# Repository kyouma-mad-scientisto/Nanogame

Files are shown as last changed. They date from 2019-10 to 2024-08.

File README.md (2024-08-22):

# Nanogame

Da einige meiner Freunde interesse am Programmieren mit Arduino zeigten, habe ich vor einiger Zeit einen kleinen Workshop organisiert und für diesen Zweck eine eigene Platine als Plattform für diverse Module konstruiert.<br />

Diese Hardware-Plattform bietet Platz für:<br />

1x Arduino Nano<br />
1x DFPlayer Mini (zur Audiowiedergabe von microSD)<br />
1x PCD8544 LC-Display<br />
1x TP4056 Li-Ion Laderegler<br />
1x Step-Up Wandler (5V für Arduino Nano)<br />

Als Grundlage sind auf der Platine 11 Tasten vorhanden, ein microSD Kartenslot sowie die benötigte Außenbeschaltung.<br />
Um IOs zu sparen, werden die Tasten über Schieberegister abgefragt, so werden nur 3 IOs benötigt.<br />

Alle noch freien IOs habe ich auf einen Pin Header auf der Rückseite gelegt.<br />

Um das ganze Testen zu können, habe ich Snake, bzw. ein Snake ähnliches Spiel, implementiert. (Siehe Demo Video und Code unter Beispiele)<br />

Hier die fehlerbehaftete erste Variante der Leiterplatte die ich noch zu Hause hergestellt habe:<br />

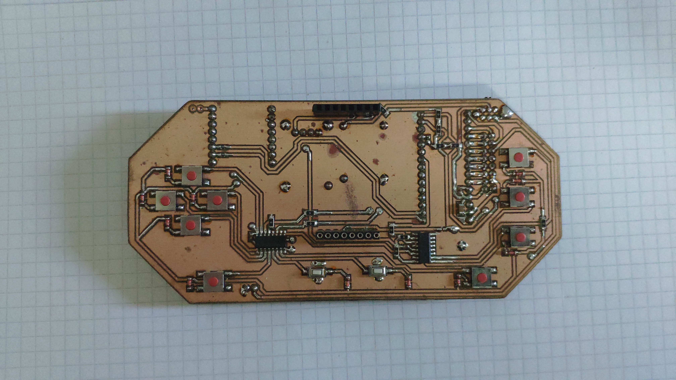
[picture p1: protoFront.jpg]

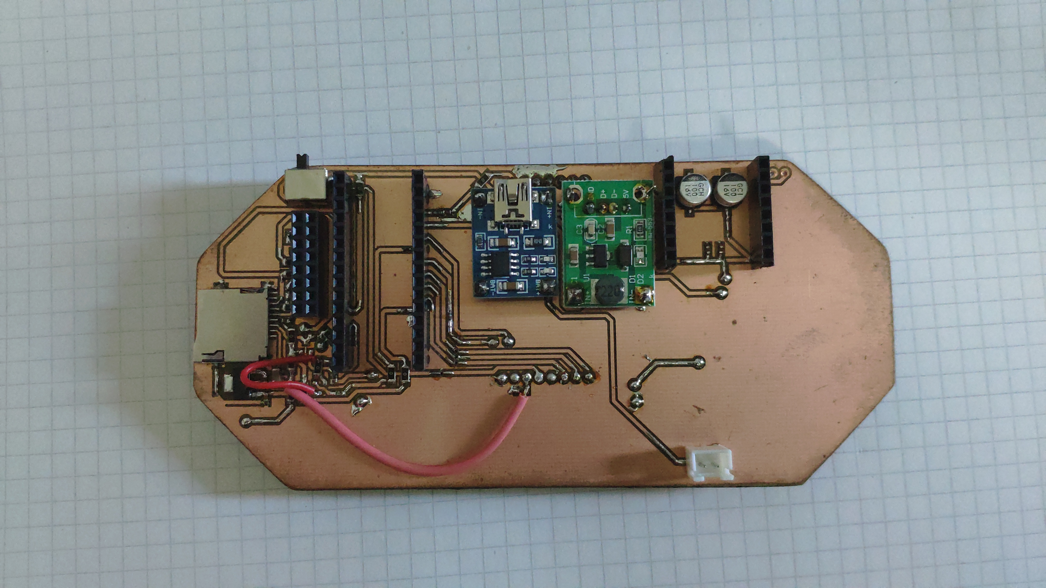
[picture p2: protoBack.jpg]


Hier nun die fertige Variante vom professionellen Leiterplattenfertiger:<br />

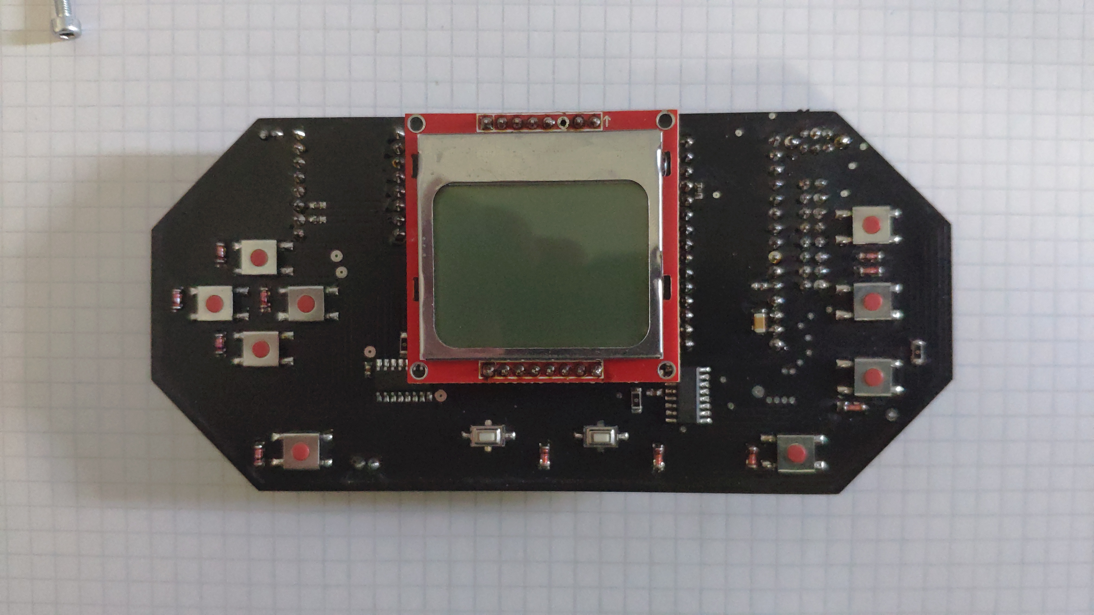
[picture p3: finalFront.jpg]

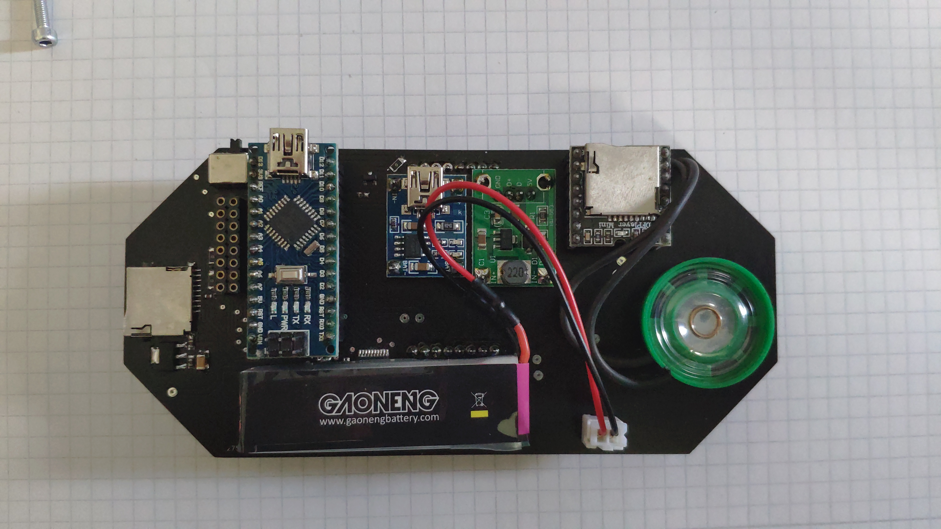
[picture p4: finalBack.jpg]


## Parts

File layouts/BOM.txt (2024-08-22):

Pos.		Bezeichnung/Bauform			Wert		Menge

1		DFPlayerMini				-		1
2		SMD Elektrolytkondensator		16V/100µF	2
3		Schottky-Diode				40V/1A		1
4		Keramikkondensator/0603			50V/100nF	10
5		Diode 1N4001/1206			50V/1A		11
6		SMD Taster 6x6mm			-		9
7		SMD Taster 6x3mm			-		2
8		PCD8544 LCD				Vcc = 3,3V	1
9		Brücken/1206				0 Ohm		12
10		IRLML2502PBF/SOT23			-		1
11		Widerstand/0603				85 Ohm		1
12		AMS1117-3.3				3,3V LDO	1
13		Keramikkondensator/1206			25V/10µF	2
14		Widerstand/0603				100kOhm		1
15		Widerstand/0603				200kOhm		1
16		JST Steckbuchse				2pol.		1
17		Schalter				2 Wechsler	1
18		Li-Ion Lademodul			500mA		1
19		Aufwärtsschaltspannungswandlermodul	5V/200mA	1
20		Widerstand/0603				1kOhm		2
21		microSD Kartenslot 			Retention	1
22		Arduino Nano 				Atmega328p	1
23		74HC595D Schieberegister		-		2
24		Pegelwandler TXS0108EPWR		bidirektional	1
25		Steckerleiste				16 pol. (2x8)	1
26		Widerstand/0603				10kOhm		1		<--- wurde auf 10kOhm geändert, im Layout als 200kOhm für Taster Eingang

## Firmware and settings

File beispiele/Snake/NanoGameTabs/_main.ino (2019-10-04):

#include <avr/interrupt.h>
#include <avr/io.h>
#include <Arduino.h>
//############################################################################################################################################################################

//Snake Instanz anlegen
Snake snake;

void setup() {
//Timer2 fuer 1ms initialisieren
  Timer2.initTimer2();
  Timer2.enableTimer2Interrupt();
//Hintergrundbeleuchtung pwm
  pwmBL.initOCR1B();
//Pegelwandler ein
  pinMode(_OE_LEVEL, OUTPUT);
  digitalWrite(_OE_LEVEL, HIGH);
//Hintergrundbeleuchtung an, halbe Helligkeit  
  pinMode(BL, OUTPUT);
  BRIGHTNESS = 127;
//LCD init,   invert, vop, tempcoef, bias  
  lcd.begin(false, 0xB1, 0x04, 0x12);
  lcd.clear();
//erster Taster check
  tasten.checkButtons();
//DFPlayer mini initialisieren
#ifdef SOUND
  Serial.begin(9600);   //set speed for Hardware  Serial pin 1 and 2 tx/rx
  myDFPlayer.begin(Serial);//select Serial to send comand to dfplayer
  myDFPlayer.EQ(DFPLAYER_EQ_ROCK);
#endif
  snake.startGame();
}
//Endlosschleife
void loop() {
  snake.runningGame();
}

ISR(TIMER2_COMPA_vect) { // called by timer2
  tasten.checkButtons();  //Aufruf 1-mal pro Millisekunde
  snake.increaseTimer();
}

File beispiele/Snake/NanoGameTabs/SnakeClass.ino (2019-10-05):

#include <Coordinates.h>
#include <EEPROM.h>
//defines fuer die Richtung in die die Schlange kriecht
#define UP 0
#define DOWN 1
#define LEFT 2
#define RIGHT 3
//LCD Aufloesung
#define X_LCD_RESOLUTION 84
#define Y_LCD_RESOLUTION 48
//Spielfeld
#define BLOCK_SIZE 3                      //groesse der Spielfeldbloecke
#define X_RESOLUTION X_LCD_RESOLUTION / BLOCK_SIZE    // 84 / 3  = 28
#define Y_RESOLUTION Y_LCD_RESOLUTION / BLOCK_SIZE    // 48 / 3  = 16
//EEPROM
#define VERIFICATION 0xff234597           //testen, ob bereits in den EEPROM geschrieben wurde
//AUDIO
#define INTRO 2
#define THEME 3
#define END 4
#define GULP 1

//############################################################################################################################################################################
class Snake {
  private:
    const uint16_t eeAddress = 4;         //die ersten 4 Byte signalisieren ob bereits eine Liste da ist
    uint32_t highscoreList[3];            //highscoreliste
    uint32_t points;                      //Punktestand
//food variablen
    Coordinates foodPosition;             //enthaelt die koordinaten des essens
    bool noFood;                          //gibt es noch essen?
    uint16_t foodTime;                    //timer fuer das essen der Schlange

    uint8_t storedBrightness;
    uint16_t blinkTime;
    bool blinkBL;
    
    uint16_t moveTime;                    //timer fuer die Bewegung der Schlange
    uint8_t moveDirection;                //signalisiert die Richtung in die die Schlange kriecht
//Positionen des Kopfes, des Schwanzes und aller anderen Segmente
    Coordinates headPosition;
    Coordinates tailPosition;
    Coordinates segmente[X_RESOLUTION*Y_RESOLUTION];
    uint16_t tailIndex;                   //aktuelles Array-Ende
//Timeouts
    const uint16_t moveTimeout = 180;     //Zeit bis sich die Schlange um ein Segment nach vorn bewegt, in millisekunden
    const uint16_t foodTimeout = 6000;    //Zeit bis das Futter verschwindet und neues erscheint, in millisekunden
    const uint16_t blinkBLtimeout = 500;
  
  public:
  Snake() {}
//main der Klasse Snake, wird kontinuierlich ausgefuehrt
  runningGame(){
    printField();
    if(moveTime >= moveTimeout) {                                   //Muss sich die Schlange fortbewegen?
      moveTime = 0;
      moveSnake();
    }
    extendSnake();                                                  //hat die Schlange etwas gefressen?
    changeDirection();                                              //Wurde die Richtung gewechselt?
    if(foodTime >= foodTimeout || noFood) {                         //War das Futter lang genug da oder wurde es gefressen?
      foodTime = 0;
      randomSeed(TCNT1);
      foodGenerator();
    }
    if(isSnakeCrossing() || tasten.getButtonCycle(buttonSelect)) {  //kreuzt sich die Schlange? Will der Nutzer das Spiel beenden?
      gameOver();
      startGame();
    }
    if(blinkBL && (blinkTime >= blinkBLtimeout)) {
      BRIGHTNESS = storedBrightness;
      blinkBL = false;
    }
  }
//Spiel vorbei
  gameOver() {
#ifdef SOUND
    myDFPlayer.stop();
    myDFPlayer.volume(24);  //Set volume value. From 0 to 30
    myDFPlayer.play(END);
#endif
    clearField();
    printField();
    lcd.printOut("Game over!", 1, 11);
    lcd.writeRect(0,9,83,2,true);
    lcd.printOut("Punkte:", 3, 0);
    lcd.printOut(String(points, DEC), 5, 0);
    lcd.renderAll();
    highscore();      //high score ggf. speichern/abrufen
//warte auf Start-Taste    
    tasten.clearAllButtons();
    while(!tasten.getButtonCycle(buttonStart)) {
    }
    tasten.clearAllButtons();
//high scores ausgeben
    clearField();
    printField();
    lcd.printOut("High scores", 1, 10);
    lcd.writeLine(0,9,83,9);
    for(uint8_t i = 0; i < 3; i++) { 
      lcd.printOut(String(i+1, DEC) + ". " + String(highscoreList[i],DEC), i+3, 0);
    }
    lcd.renderAll(); 
//warte auf Start-Taste    
    tasten.clearAllButtons();
    while(!tasten.getButtonCycle(buttonStart)) {
    }
    tasten.clearAllButtons();
  }
//Spiel initialisieren
  startGame() {
    blinkBL = false;
    points = 0;
    noFood = false;
    foodTime = 0;
    moveTime = 0;
//LCD loeschen und von vorn
    lcd.clear(false);
    lcd.printOut("Druecke Start",2, 3);
    lcd.writeRect(0,6,83,11,false);
    lcd.renderLine(); 
#ifdef SOUND
    myDFPlayer.volume(30);  //Set volume value. From 0 to 30
    myDFPlayer.loop(INTRO);
#endif
    while(!tasten.getButtonCycle(buttonStart)) {
    }
    randomSeed(TCNT1);
    clearField();
    tailIndex = 3;
    headPosition.setCoordinates(14,8);    //Position Kopf festlegen
    segmente[0] = headPosition;           //Schattenkopie
    segmente[1].setCoordinates(15,8);     //zweites Segment
    segmente[2].setCoordinates(16,8);     //drittes Segment"
    foodGenerator();
    moveDirection = LEFT;                 //Startrichtung links
    printSnake();                         //Schlange ausgeben
    tasten.clearAllButtons();
    foodTime = 0;                         //food timer auf 0
#ifdef SOUND
    myDFPlayer.stop();
    myDFPlayer.volume(14);  //Set volume value. From 0 to 30
    myDFPlayer.loop(THEME);
#endif
    moveTime = moveTimeout;               //move timer auf 0 ACHTUNG! BEENDET SPIEL SOFORT!!!
  }
//blink
inline blinkBacklight() {
  if(!blinkBL) {
    storedBrightness = BRIGHTNESS;
    BRIGHTNESS = 255;
    blinkBL = true;
    blinkTime = 0;
  }
}
//highscore speichern und Liste laden
  highscore() {
    long verify;
    bool store = false;
    EEPROM.get(0, verify);
    if(verify == VERIFICATION) {
      EEPROM.get(eeAddress, highscoreList);
      for(uint8_t i = 0; i < 3; i++) {
        if(highscoreList[i] < points) {
          highscoreList[i] = points;
          i = 3;
          store = true;
        }
      }
    } else {
        for(uint8_t i = 1; i < 3; i++) {
          highscoreList[i] = 0;
        }
        highscoreList[0] = points;
      EEPROM.put(0, VERIFICATION);
    }
    if(store) EEPROM.put(eeAddress, highscoreList);
  }  
//pruefen ob Schlange sich kreuzt
  bool isSnakeCrossing() {
    bool crossing = false;
    for(uint16_t i = 0; i < tailIndex; i++) {
      if( (segmente[i].getX() == headPosition.getX()) && (segmente[i].getY() == headPosition.getY()) ) {
          crossing = true;
        }
    }
    return crossing;
  }
//Schlange erweitern
  extendSnake() {
    if((foodPosition.getX() == headPosition.getX()) && (foodPosition.getY() == headPosition.getY())) {
      tailIndex++;
      blinkBacklight();
      for(int16_t i = tailIndex - 1; i > 0; i--) {
        segmente[i] = segmente[i-1];
      }
      points += foodTime;
      noFood = true; /*
#ifdef SOUND
    myDFPlayer.play(GULP);
#endif */
    }
  }
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

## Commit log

2019-10-04 Alle aktuellen Projektdateien
    [Gamepad_PCD8544_v1.2_JLC_copper_bottom.gbr, Gamepad_PCD8544_v1.2_JLC_copper_top.gbr, Gamepad_PCD8544_v1.2_JLC_outline.gbr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]
2019-10-05 -Layout aktualisiert -Sound hinzugefuegt, ABER problem mit advert besteht weiterhin
    [Gamepad_PCD8544_v1.2_JLC_copper_bottom.gbr, Gamepad_PCD8544_v1.2_JLC_copper_top.gbr, Gamepad_PCD8544_v1.2_JLC_silkscreen_bottom.gbr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]
2024-08-22 Bilder und Demovideo hinzugefügt
